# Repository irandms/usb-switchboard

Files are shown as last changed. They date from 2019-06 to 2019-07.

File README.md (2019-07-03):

# USB Switchboard Bonnet

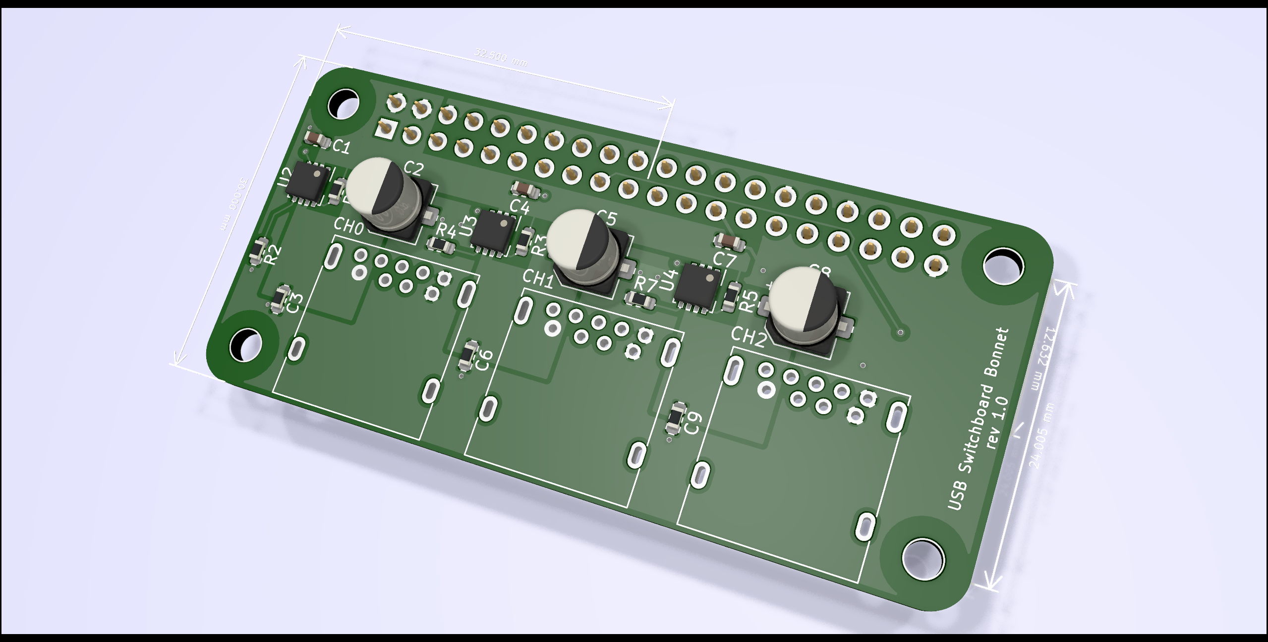
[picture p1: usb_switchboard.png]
usb_switchboard


This repository houses the KiCad design files for a Raspberry Pi Zero Bonnet
board. The system provides three independently controlled USB ports, which can
be selectively enabled or disabled for power delivery purposes via 3 GPIO pins
on the Pi host. The data pins for all receptacles are unused.

In addition to being able to digitally control each USB port, each port has
suppport for overcurrent protection via the [Texas Instruments TPS2556 IC](https://www.ti.com/product/TPS2556)
, capping out to ~500 mA per port. Fault/short circuit and temperature 
protection is also provided by the TPS2556.

When tested using an Pac-Man Silhouette LED Blue Ghost, it can provide PWM 
diming at ~500 Hz or faster depending on the period, with an untested upper
bound.

The initial set of prototype boards were made at [OSH Park](https://oshpark.com/shared_projects/6m9zgemo) using their 2oz Copper service, as the current through
the 5V input net from the Pi host could be fairly high depending on the
state of each of the ports and the devices connected to them.

bill-of-materials.csv contains a DigiKey-importable Bill of Materials that
has every component required on the PCB. Notably missing are the HAT EEPROM and
related passives, which can be found on the underside of the board.

The three channels can be enabled/disabled through the following GPIO pins:

| GPIO Pin | Channel |
| --- |:---:|
| GPIO2 | CH0 |
| GPIO10 | CH1 |
| GPIO11 | CH2 |

## NOTE:
I have not worked on including an EEPROM for this board to conform to the 
official Raspberry Pi Bonnet/HAT spec.

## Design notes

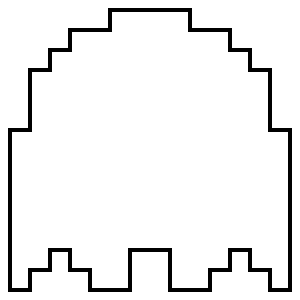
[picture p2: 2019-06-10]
fp/blinky_outline.png

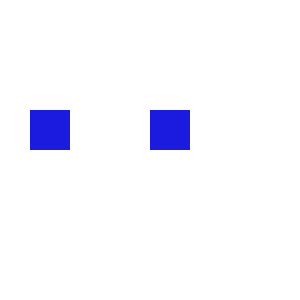
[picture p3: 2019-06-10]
fp/blinky_eyes.png

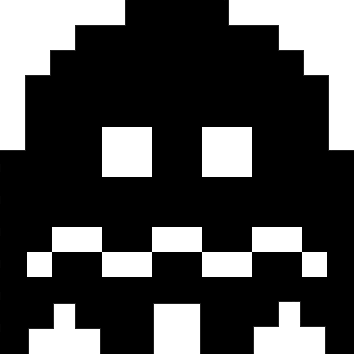
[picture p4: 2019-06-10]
fp/eaten_body.png

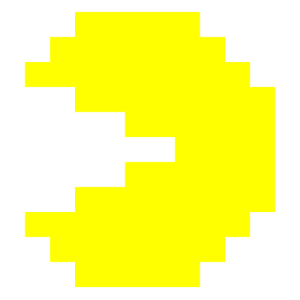
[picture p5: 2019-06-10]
fp/pacman.bmp

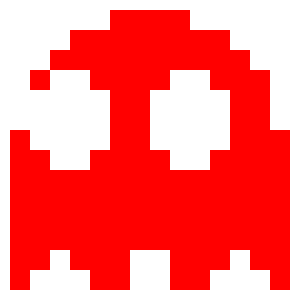
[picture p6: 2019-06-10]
fp/blinky_body.bmp

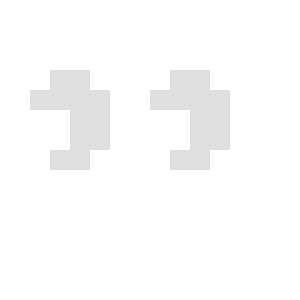
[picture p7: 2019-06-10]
fp/blinky_eyes_outer.png

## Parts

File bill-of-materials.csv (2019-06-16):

Manufacturer Part Number | Manufacturer | Digi-Key Part Number | Customer Reference | Reference Designator | Packaging | Part Status | Quantity | Unit Price | Extended Price | Quantity Available | Mfg Std Lead Time | Description | RoHS Status | Lead Free Status | REACH Status
UCM0J221MCL1GS | Nichicon | 493-17593-1-ND |  | C2, C5, C8 | Cut Tape (CT) | Active | 3 | 0.47000 | $1.41 | 1640 | 20 Weeks | CAP ALUM 220UF 20% 6.3V SMD | RoHS Compliant | Lead free | REACH Unaffected
TPS2556DRBR | Texas Instruments | 296-39382-1-ND |  | U2, U3, U4 | Cut Tape (CT) | Active | 3 | 2.14000 | $6.42 | 3075 | 16 Weeks | IC PWR DIST SWITCH ADJ 8SON | RoHS Compliant | Lead free | REACH Unaffected
RR0816P-104-D | Susumu | RR08P100KDCT-ND |  | R1, R3, R5 | Cut Tape (CT) | Active | 3 | 0.11000 | $0.33 | 511988 | 16 Weeks | RES SMD 100K OHM 0.5% 1/16W 0603 | RoHS Compliant | Lead free | Not Available
CL10B104KO8NNNC | Samsung Electro-Mechanics | 1276-1005-1-ND |  | C1, C4, C7 | Cut Tape (CT) | Active | 3 | 0.10000 | $0.30 | 13872104 | Not Available | CAP CER 0.1UF 16V X7R 0603 | RoHS Compliant | Lead free | REACH Unaffected
CL10A106MQ8NNNC | Samsung Electro-Mechanics | 1276-1119-1-ND |  | C3, C6, C9 | Cut Tape (CT) | Active | 3 | 0.15000 | $0.45 | 3761785 | Not Available | CAP CER 10UF 6.3V X5R 0603 | RoHS Compliant | Lead free | REACH Unaffected
RC0603FR-07187KL | Yageo | 311-187KHRCT-ND |  | R2, R4, R7 | Cut Tape (CT) | Active | 3 | 0.10000 | $0.30 | 378761 | 16 Weeks | RES SMD 187K OHM 1% 1/10W 0603 | RoHS Compliant | Lead free | REACH Unaffected
0483930003 | Molex | WM10413CT-ND |  | J1, J2, J4 | Cut Tape (CT) | Active | 3 | 1.74000 | $5.22 | 5014 | 14 Weeks | CONN RCPT USB3.0 TYPEA 9POS R/A | RoHS Compliant | Lead free | REACH Unaffected
PPPC202LFBN-RC | Sullins Connector Solutions | S7123-ND |  | J3 | Tray | Active | 1 | 2.38000 | $2.38 | 9781 | 5 Weeks | CONN HDR 40POS 0.1 GOLD PCB | RoHS Compliant | Lead free | REACH Unaffected

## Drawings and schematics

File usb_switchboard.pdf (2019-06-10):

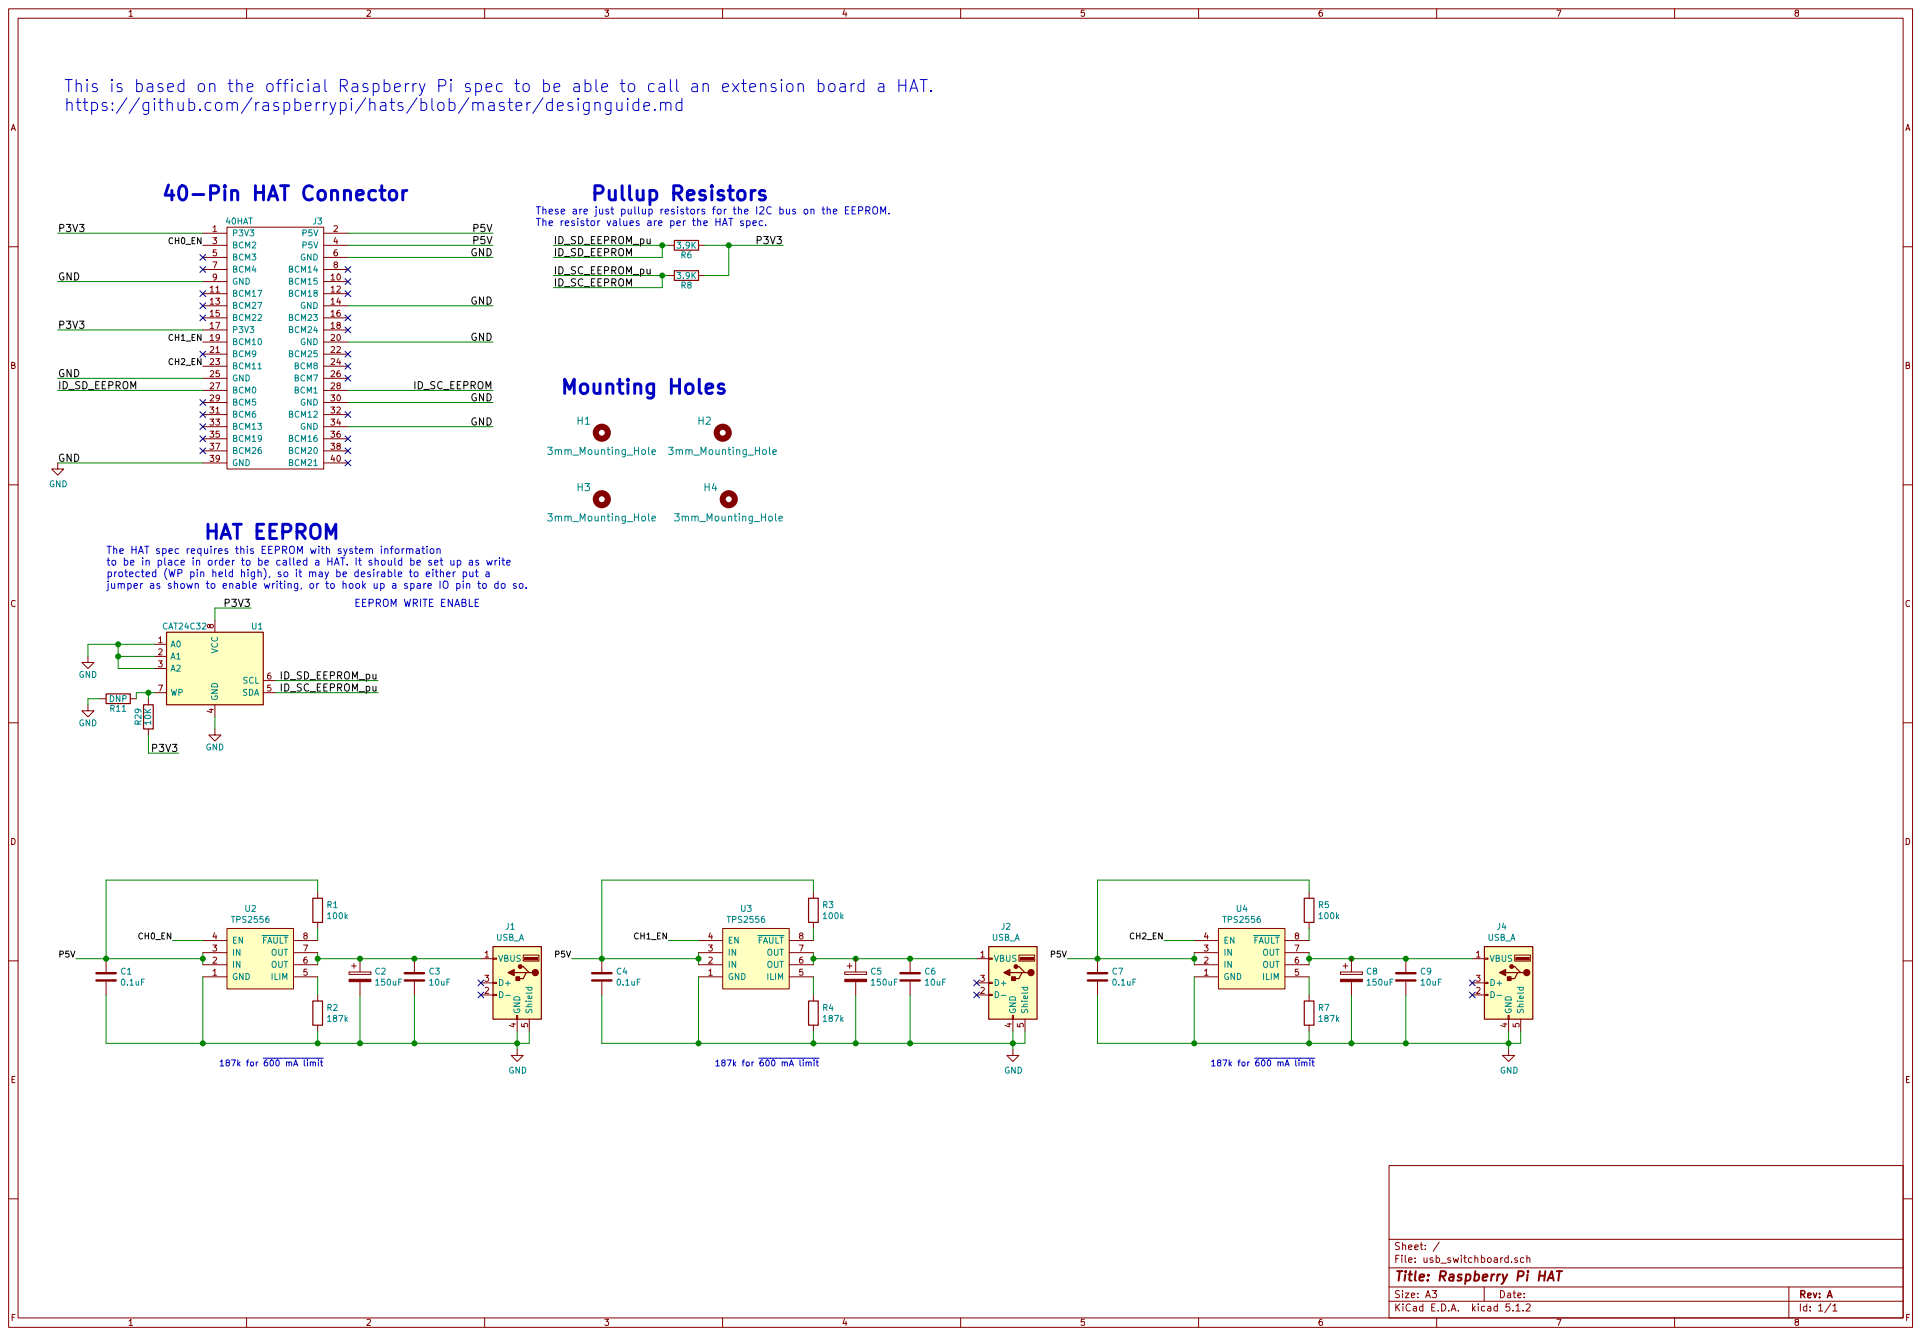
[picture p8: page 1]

This is based on the official Raspberry Pi spec to be able to call an extension board a HAT.
https://github.com/raspberrypi/hats/blob/master/designguide.md

These are just pullup resistors for the I2C bus on the EEPROM.
The resistor values are per the HAT spec.
ID_SD_EEPROM_pu
ID_SD_EEPROM
ID_SC_EEPROM_pu
ID_SC_EEPROM

The HAT spec requires this EEPROM with system information
to be in place in order to be called a HAT. It should be set up as write
protected (WP pin held high), so it may be desirable to either put a
jumper as shown to enable writing, or to hook up a spare IO pin to do so.

File: usb_switchboard.sch Sheet: /
Id: 1/1 Title: Raspberry Pi HAT

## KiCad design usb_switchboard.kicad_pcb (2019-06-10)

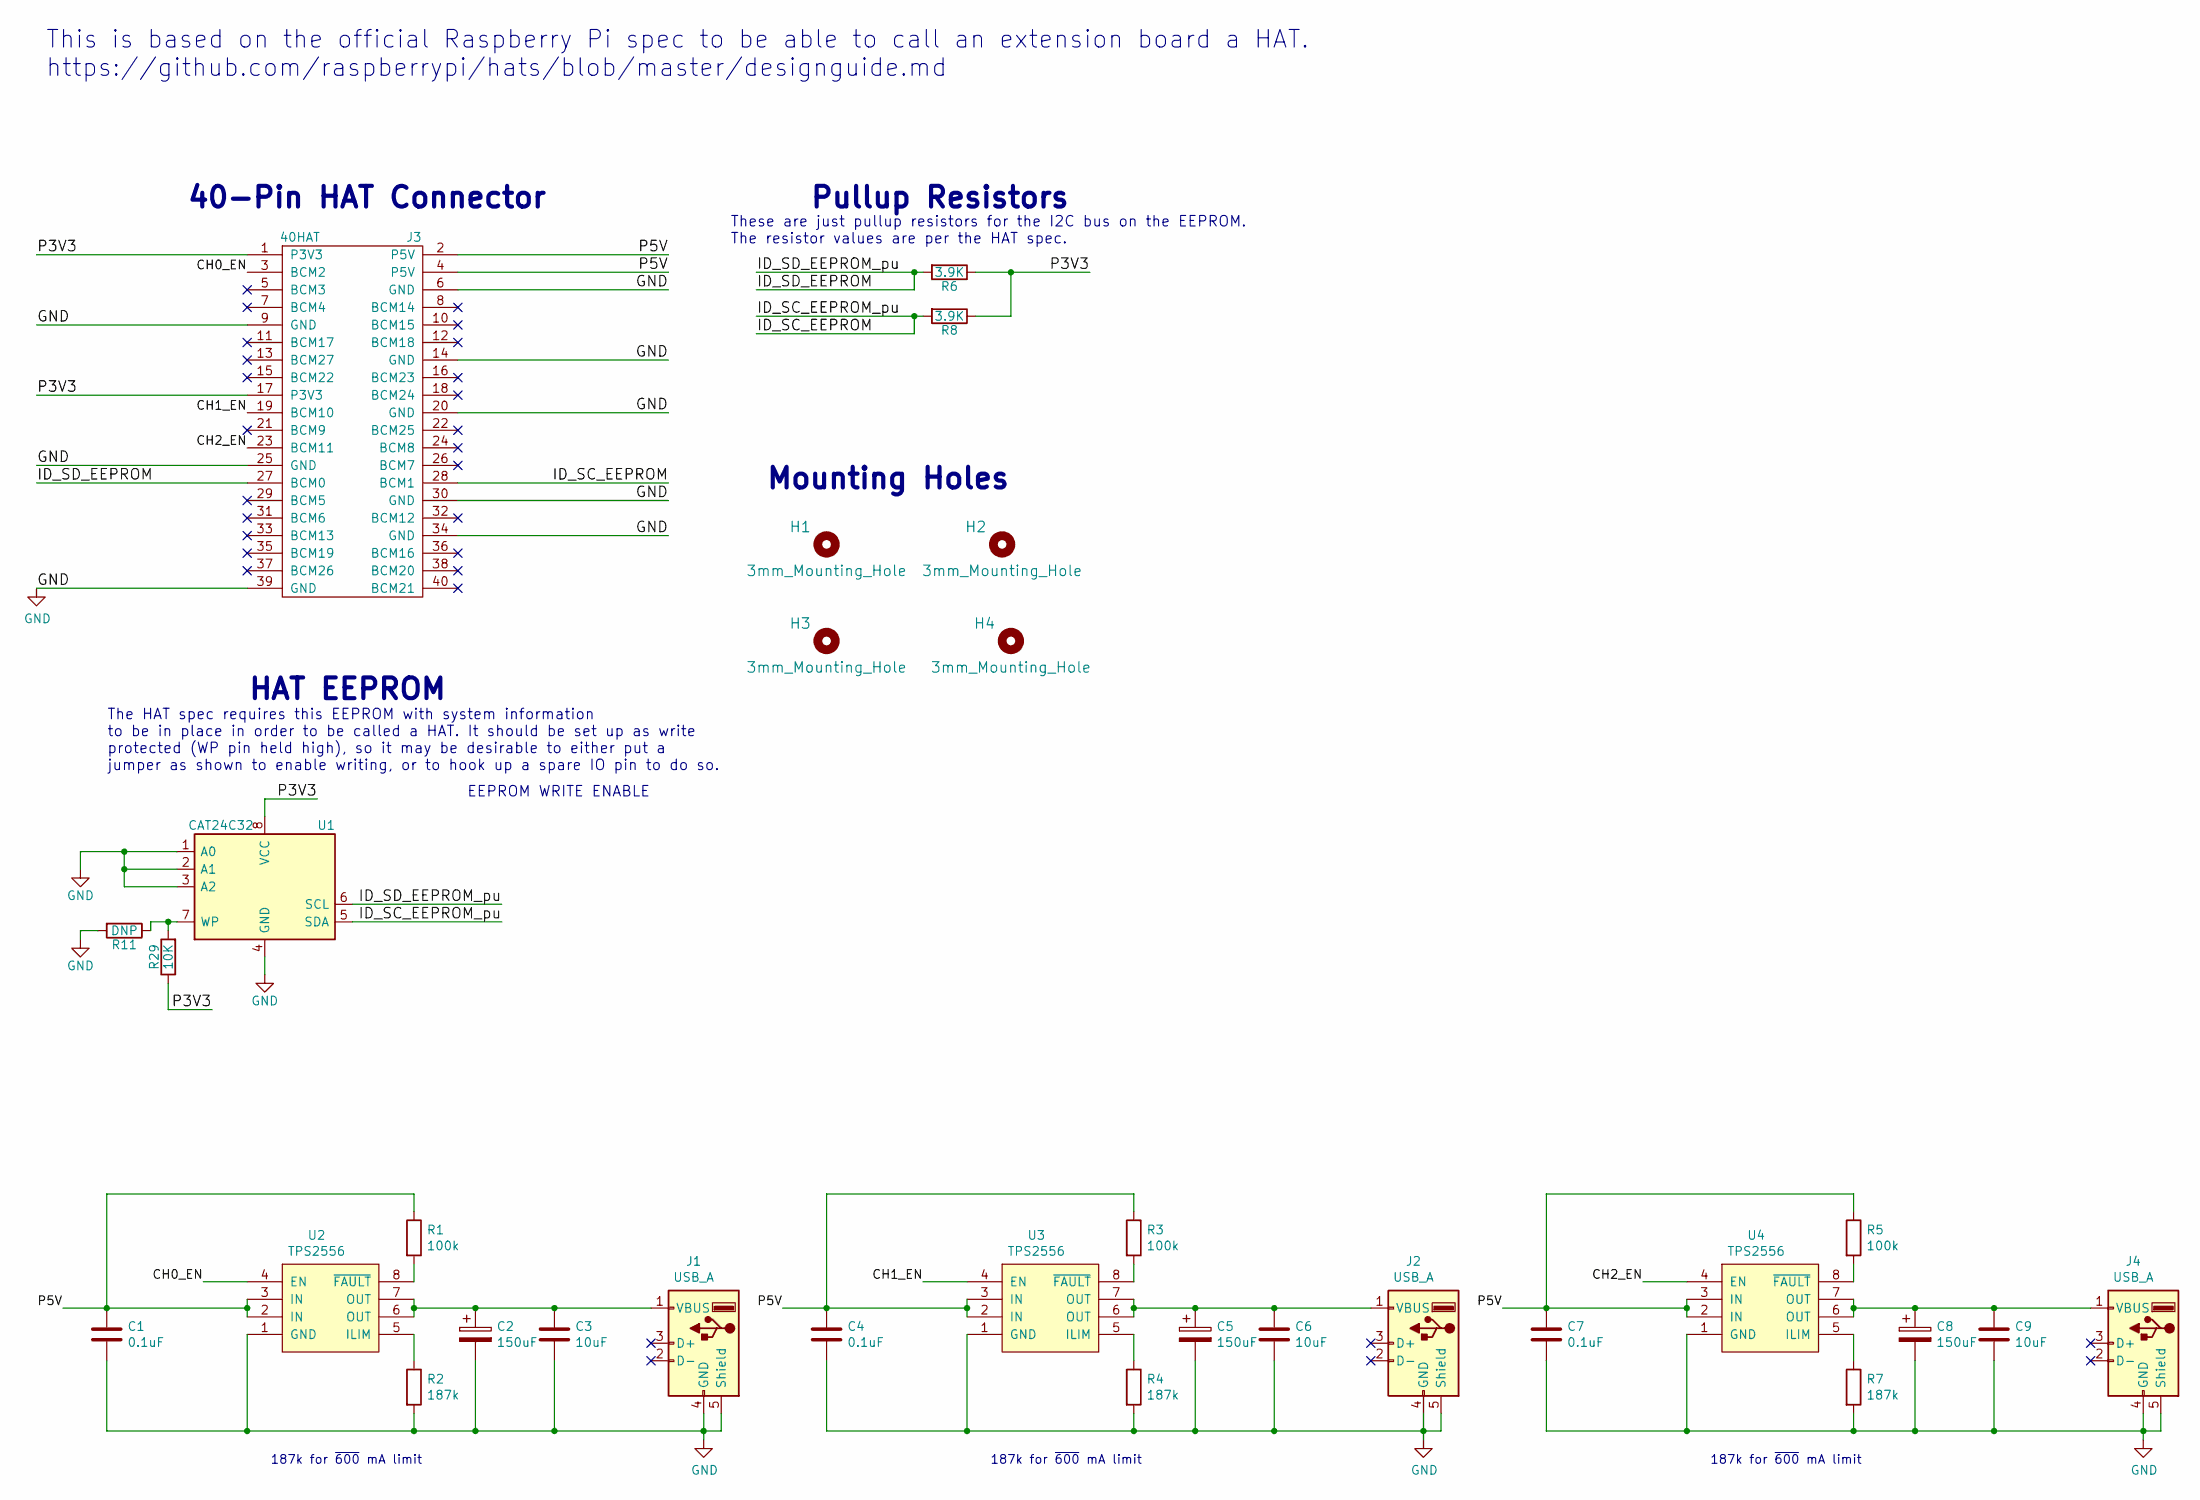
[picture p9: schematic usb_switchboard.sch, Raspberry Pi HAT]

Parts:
C1, C4, C7: 0.1uF; C_0603_1608Metric
C2, C5, C8: 150uF; CP_Elec_5x5.3
C3, C6, C9: 10uF; R_0603_1608Metric
H1, H2, H3, H4: 3mm_Mounting_Hole; NPTH_3mm_ID
J1, J2, J4: USB_A; USB3_A_Molex_48393-001
J3: 40HAT; PinSocket_2x20_P2.54mm_Vertical
R1, R3, R5: 100k; R_0603_1608Metric
R2, R4, R7: 187k; R_0603_1608Metric
R6, R8: 3.9K; R_0603_1608Metric_Pad0.84x1.00mm_HandSolder
R11: DNP; R_0603_1608Metric_Pad0.84x1.00mm_HandSolder
R29: 10K; R_0603_1608Metric_Pad0.84x1.00mm_HandSolder
U1: CAT24C32; SOIC-8_3.9x4.9mm_P1.27mm
U2, U3, U4: TPS2556; Texas_S-PVSON-N8_ThermalVias

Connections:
/CH0_EN: J3.3 (BCM2), U2.4 (EN)
/CH1_EN: J3.19 (BCM10), U3.4 (EN)
/CH2_EN: J3.23 (BCM11), U4.4 (EN)
/ID_SC_EEPROM: J3.28 (BCM1), R8.2, U1.5 (SDA)
/ID_SD_EEPROM: J3.27 (BCM0), R6.2, U1.6 (SCL)
/P3V3: J3.1 (P3V3), J3.17 (P3V3), R6.1, R8.1, R29.1, U1.8 (VCC)
/P5V: C1.1, C4.1, C7.1, J3.2 (P5V), J3.4 (P5V), R1.1, R3.1, R5.1, U2.2 (IN), U2.3 (IN), U3.2 (IN), U3.3 (IN), U4.2 (IN), U4.3 (IN)
GND: C1.2, C2.2, C3.2, C4.2, C5.2, C6.2, C7.2, C8.2, C9.2, J1.4 (GND), J1.5 (Shield), J2.4 (GND), J2.5 (Shield), J3.6 (GND), J3.9 (GND), J3.14 (GND), J3.20 (GND), J3.25 (GND), J3.30 (GND), J3.34 (GND), J3.39 (GND), J4.4 (GND), J4.5 (Shield), R2.2, R4.2, R7.2, R11.2, U1.1 (A0), U1.2 (A1), U1.3 (A2), U1.4 (GND), U2.1 (GND), U2.9 (PAD), U3.1 (GND), U3.9 (PAD), U4.1 (GND), U4.9 (PAD); also elsewhere on the board
unnamed 8: C2.1, C3.1, J1.1 (VBUS), U2.6 (OUT), U2.7 (OUT); also elsewhere on the board
unnamed 9: C5.1, C6.1, J2.1 (VBUS), U3.6 (OUT), U3.7 (OUT); also elsewhere on the board
unnamed 10: C8.1, C9.1, J4.1 (VBUS), U4.6 (OUT), U4.7 (OUT); also elsewhere on the board
unnamed: R1.2, U2.8 (~FAULT)
unnamed: R2.1, U2.5 (ILIM)
unnamed: R3.2, U3.8 (~FAULT)
unnamed: R4.1, U3.5 (ILIM)
unnamed: R5.2, U4.8 (~FAULT)
unnamed: R7.1, U4.5 (ILIM)
unnamed: R11.1, R29.2, U1.7 (WP)

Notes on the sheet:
EEPROM WRITE ENABLE
Pullup Resistors
HAT EEPROM
Mounting Holes
40-Pin HAT Connector
The HAT spec requires this EEPROM with system information to be in place in order to be called a HAT. It should be set up as write protected (WP pin held high), so it may be desirable to either put a jumper as shown to enable writing, or to hook up a spare IO pin to do so.
These are just pullup resistors for the I2C bus on the EEPROM. The resistor values are per the HAT spec.
This is based on the official Raspberry Pi spec to be able to call an extension board a HAT. https://github.com/raspberrypi/hats/blob/master/designguide.md
187k for ~600 mA limit

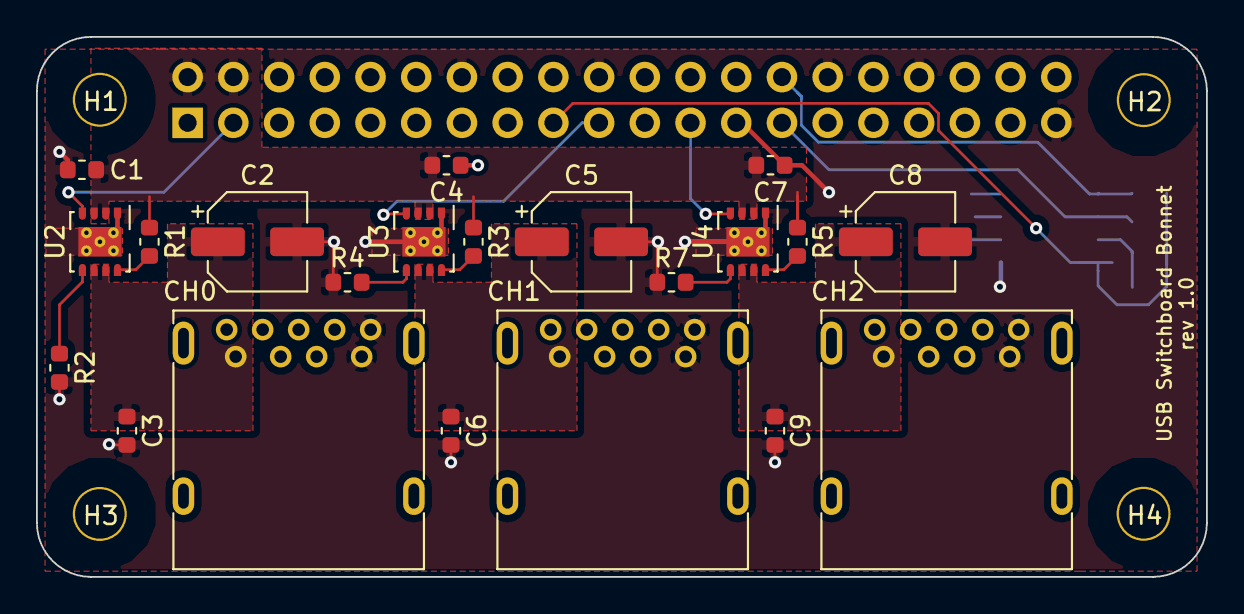
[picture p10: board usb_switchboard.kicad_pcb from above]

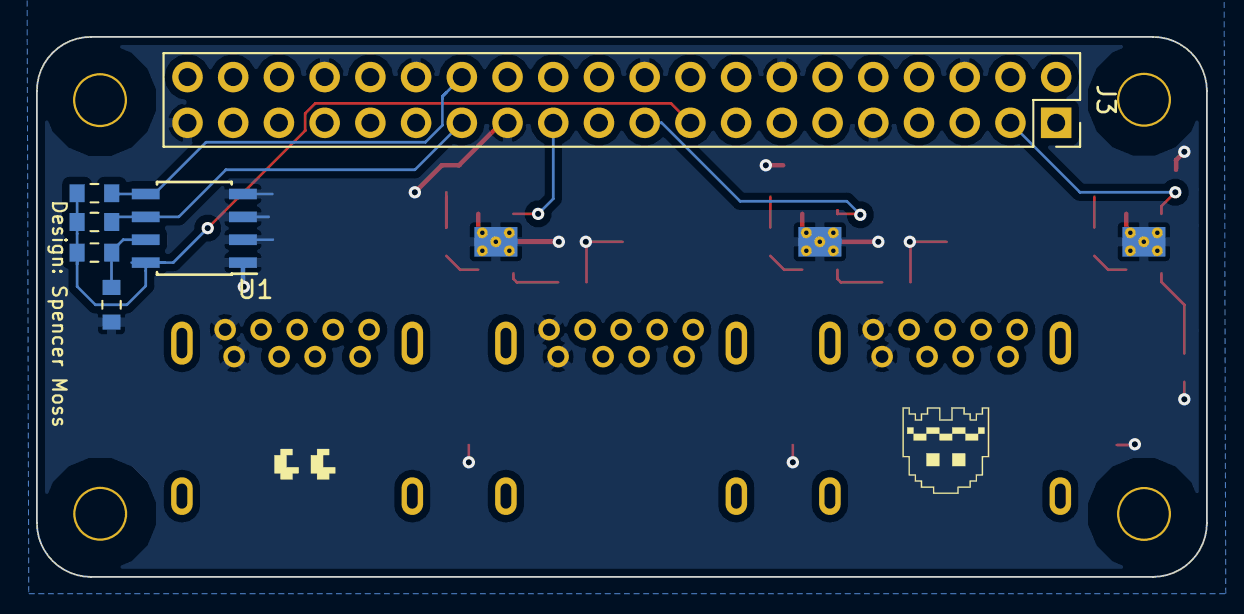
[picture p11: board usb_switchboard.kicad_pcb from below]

Board: 2 copper layers, 65.0 x 30.0 mm, 31 parts (6 on the bottom side), 18 nets.

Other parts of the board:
CH0, CH1, CH2: USB_A; USB3_A_Molex_48393-001

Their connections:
GND: CH0.4, CH0.5, CH1.4, CH1.5, CH2.4, CH2.5; also elsewhere on the board
unnamed 8: CH0.1; also elsewhere on the board
unnamed 9: CH1.1; also elsewhere on the board
unnamed 10: CH2.1; also elsewhere on the board

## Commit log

2019-06-10 Finished rev 1.0
    [usb_switchboard.kicad_pcb, usb_switchboard.sch]
2019-06-10 Add schematic PDF
2019-06-16 Updated README and added BoM
    [bill-of-materials.csv]
